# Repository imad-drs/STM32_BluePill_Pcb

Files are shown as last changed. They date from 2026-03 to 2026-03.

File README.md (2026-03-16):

# STM32_BluePill_Pcb
A custom STM32F103C8T6 development board designed in KiCad

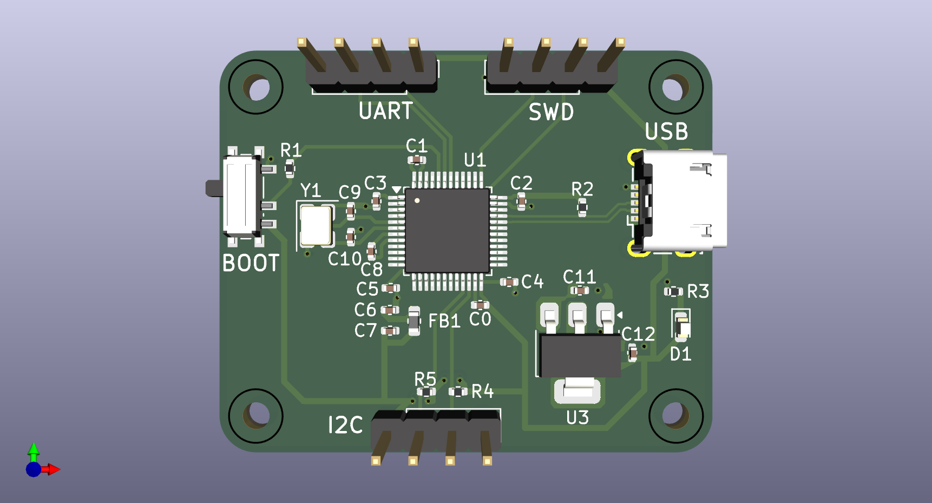
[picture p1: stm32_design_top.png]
Board Render
 

⚠️ Disclaimer: First PCB Project
**Please note:** This is my very first custom PCB design! I reverse-engineered the popular "Blue Pill" board to design this custom circuit in KiCad. It was created as a personal learning exercise to understand the bridge between embedded software and physical hardware. While I put a lot of effort into following best practices, there may be errors. **This project should not be used as an official hardware reference.**

## 🛠️ Project Overview
This repository contains the KiCad project files for a custom microcontroller development board based on the **STM32F103C8T6** (ARM Cortex-M3). 

### Hardware Specifications & Features:
* **PCB Stackup:** Routed on a standard 2-layer board.
* **Connectivity & Debugging:** Includes a dedicated **SWD (Serial Wire Debug)** header for easy flashing/debugging, plus broken-out **UART** and **I2C** pins for external sensor communication.
* **USB Interface:** Integrated Micro-USB Type-B connector for power and data.
* **Clocking:** External crystal oscillator circuit included for precise timing and USB synchronization.
* **User Interface:** Includes a dedicated BOOT button for flashing/configuration and a Power indicator LED.
* **Signal Integrity:** Robust power routing with separated digital and analog ground planes (where applicable).

## ⚡ Technical Deep Dive: Decoupling Capacitors
One of the primary focuses of this project was understanding and implementing proper power delivery. Because microcontrollers switch states millions of times per second, they require instantaneous bursts of current. Traces and power supplies have inherent inductance and cannot deliver this current fast enough, potentially causing the system to crash. 

To ensure stability, I implemented a strict decoupling strategy:
* **Local Decoupling (100nF):** Placed as close as physically possible to each `VDD` and `VBAT` pin. These act as tiny, instant energy reservoirs to handle high-frequency switching.
* **Bulk Decoupling (10uF):** Placed near the microcontroller to act as a larger, general energy reservoir for the IC.
* **Analog Filtering (VDDA):** The analog supply pin is highly sensitive to digital noise. I isolated it from the main digital 3.3V rail using a ferrite bead (120Ω at 100MHz) flanked by a 1uF and 10nF parallel capacitor network to protect the internal Analog-to-Digital Converters (ADCs).

## 📂 Files Included
* Core KiCad project files (`.kicad_pro`, `.kicad_sch`, `.kicad_pcb`).
* `Schematic.pdf`: Exported PDF of the logical circuit map.

---
*Designed by Drias Imad Eddine *

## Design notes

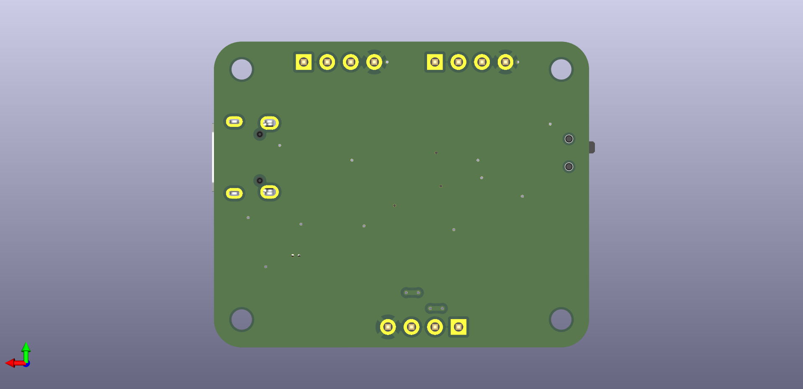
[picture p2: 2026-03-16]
stm32_design_bottom.png

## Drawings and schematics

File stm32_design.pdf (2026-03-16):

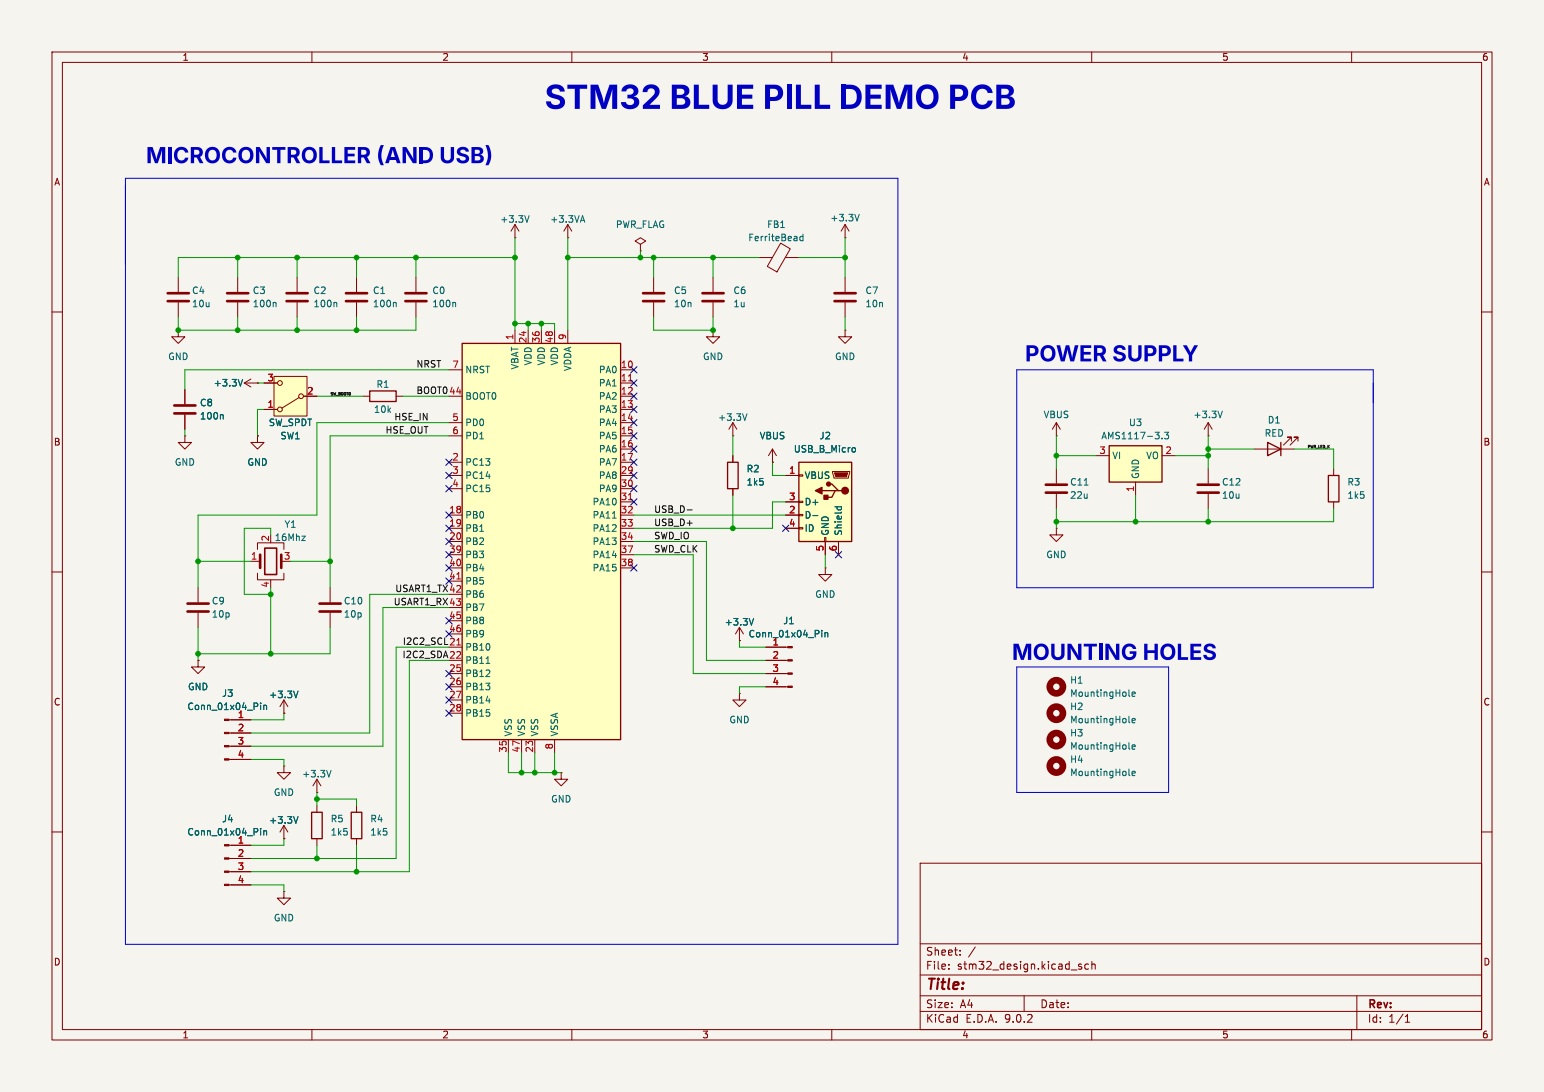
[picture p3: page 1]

1 VSS 47 VDD 24 VSS 23 VDD 36 VDD 48 VSSA

Id: 1/1 Title: File: stm32_design.kicad_sch Sheet: /

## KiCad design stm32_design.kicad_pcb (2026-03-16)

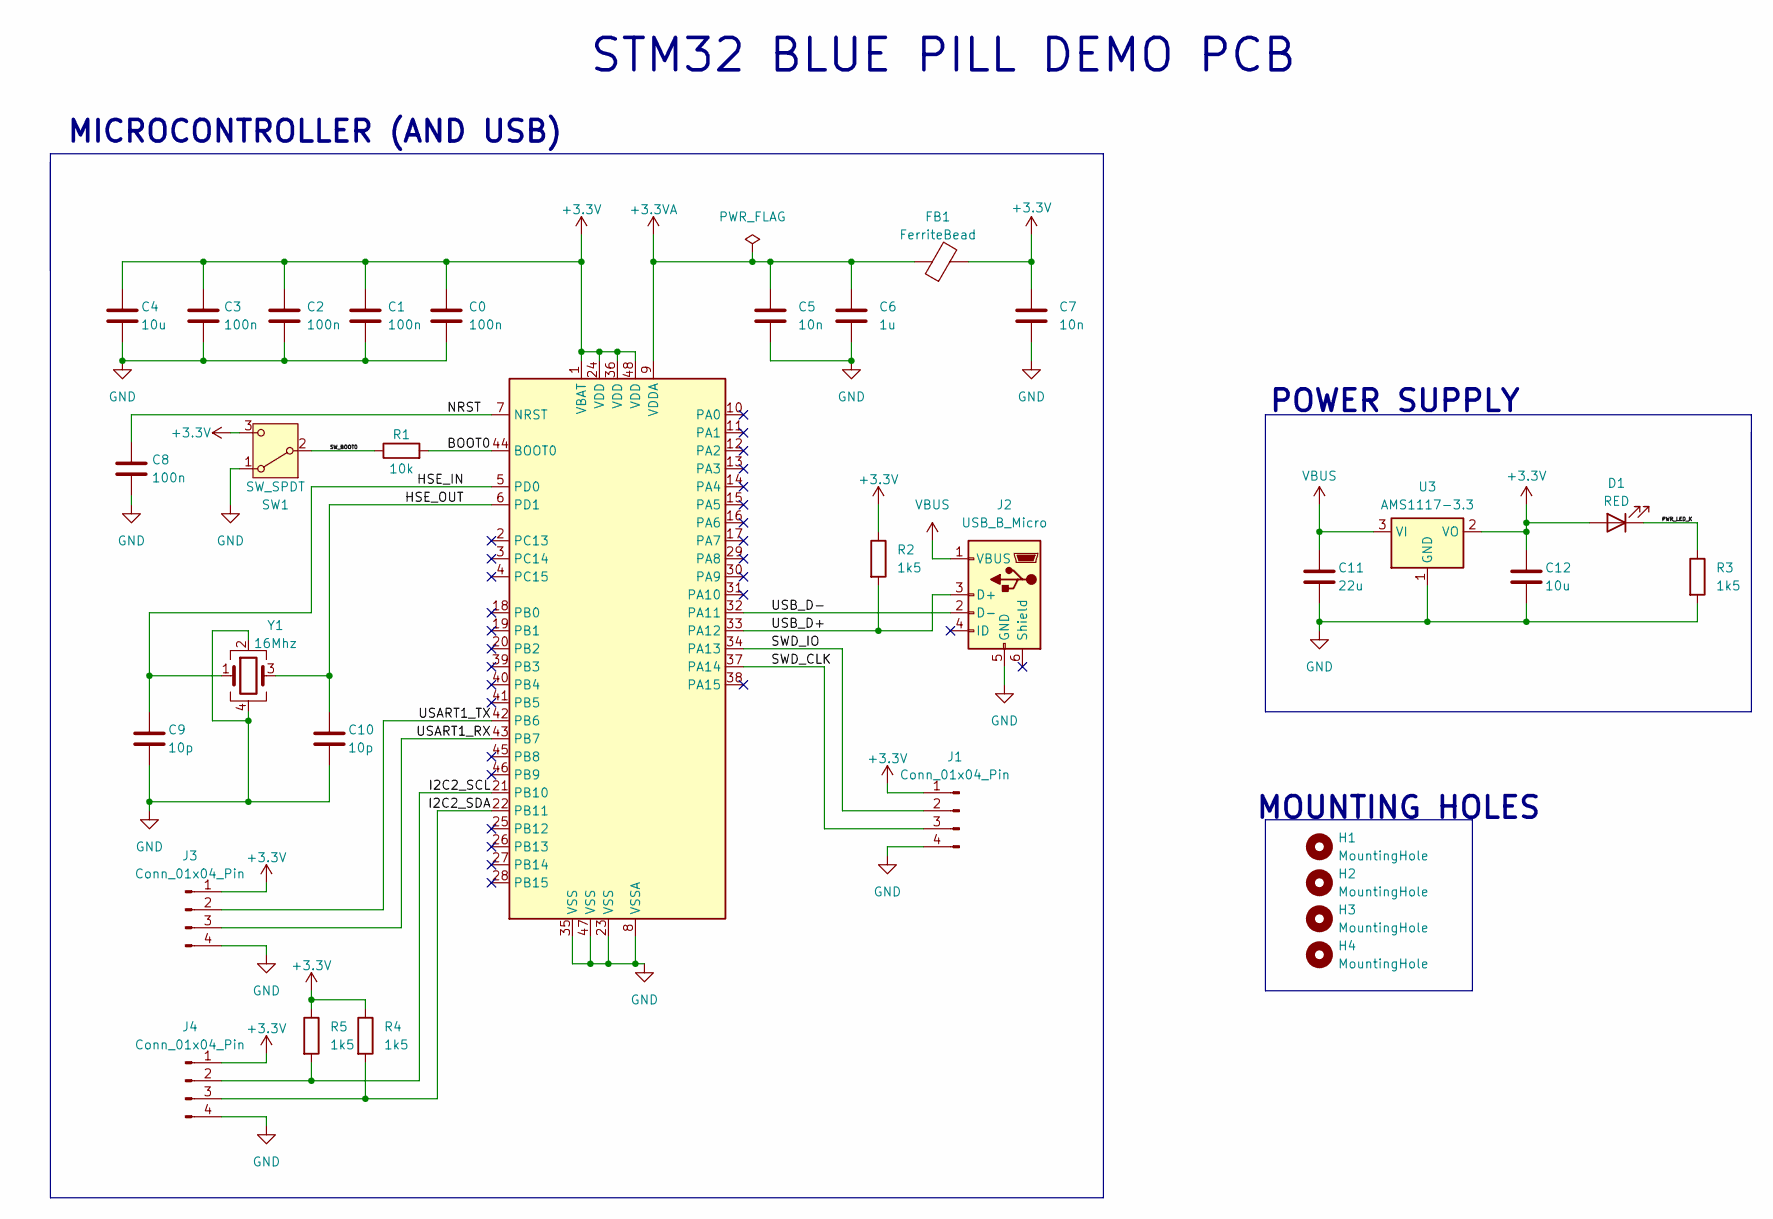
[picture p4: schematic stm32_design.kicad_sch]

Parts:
C0, C1, C2, C3, C8: 100n; C_0402_1005Metric
C4, C12: 10u; C_0402_1005Metric
C5, C7: 10n; C_0402_1005Metric
C6: 1u; C_0402_1005Metric
C9, C10: 10p; C_0402_1005Metric
C11: 22u; C_0402_1005Metric
D1: RED; LED_0603_1608Metric
FB1: FerriteBead; L_0603_1608Metric
H1, H2, H3, H4: MountingHole; MountingHole_2.2mm_M2
J1, J3, J4: Conn_01x04_Pin; PinHeader_1x04_P2.54mm_Vertical
J2: USB_B_Micro; USB_Micro-B_Wuerth_629105150521
R1: 10k; R_0402_1005Metric
R2, R3, R4, R5: 1k5; R_0402_1005Metric
SW1: SW_SPDT; SW_SPDT_PCM12
U1: STM32F103C8Tx; LQFP-48_7x7mm_P0.5mm
U3: AMS1117-3.3; SOT-223-3_TabPin2
Y1: 16Mhz; Crystal_SMD_3225-4Pin_3.2x2.5mm

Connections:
+3.3V: C0.1, C1.1, C2.1, C3.1, C4.1, C7.1, C12.1, D1.2 (A), FB1.2, J1.1, J3.1, J4.1, R2.1, R4.1, R5.1, SW1.3 (C), U1.1 (VBAT), U1.24 (VDD), U1.36 (VDD), U1.48 (VDD), U3.2 (VO)
+3.3VA: C5.1, C6.1, FB1.1, U1.9 (VDDA)
/BOOT0: R1.2, U1.44 (BOOT0)
/HSE_IN: C9.1, U1.5 (PD0), Y1.1
/HSE_OUT: C10.1, U1.6 (PD1), Y1.3
/I2C2_SCL: J4.2, R5.2, U1.21 (PB10)
/I2C2_SDA: J4.3, R4.2, U1.22 (PB11)
/NRST: C8.1, U1.7 (NRST)
/PWR_LED_K: D1.1 (K), R3.1
/SWD_CLK: J1.3, U1.37 (PA14)
/SWD_IO: J1.2, U1.34 (PA13)
/SW_BOOT0: R1.1, SW1.2 (B)
/USART1_RX: J3.3, U1.43 (PB7)
/USART1_TX: J3.2, U1.42 (PB6)
/USB_D+: J2.3 (D+), R2.2, U1.33 (PA12)
/USB_D-: J2.2 (D-), U1.32 (PA11)
GND: C0.2, C1.2, C2.2, C3.2, C4.2, C5.2, C6.2, C7.2, C8.2, C9.2, C10.2, C11.2, C12.2, J1.4, J2.5 (GND), J3.4, J4.4, R3.2, SW1.1 (A), U1.8 (VSSA), U1.23 (VSS), U1.35 (VSS), U1.47 (VSS), U3.1 (GND), Y1.2, Y1.4
VBUS: C11.1, J2.1 (VBUS), U3.3 (VI)

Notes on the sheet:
STM32 BLUE PILL DEMO PCB
POWER SUPPLY
MOUNTING HOLES
MICROCONTROLLER (AND USB)

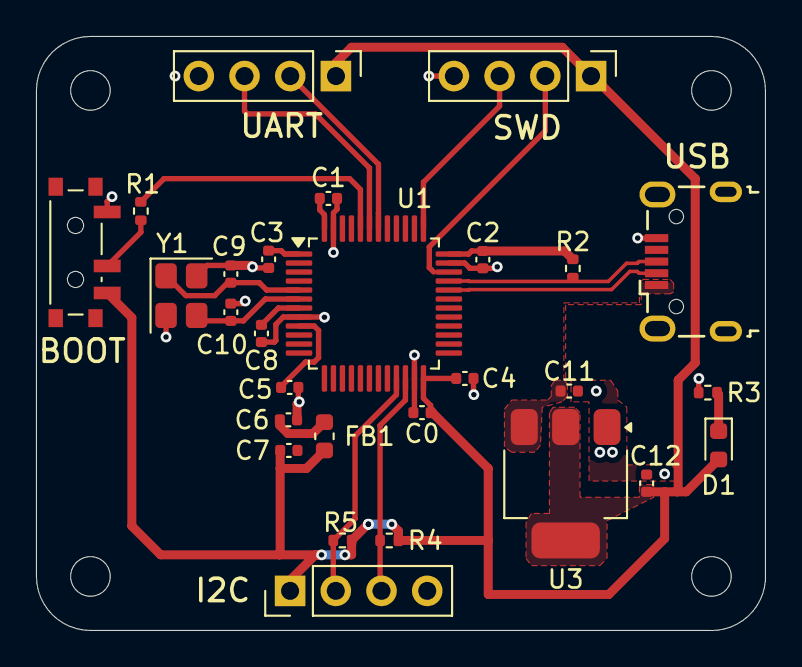
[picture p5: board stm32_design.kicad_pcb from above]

Board: 2 copper layers, 40.5 x 33.0 mm, 32 parts (0 on the bottom side), 18 nets.

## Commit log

2026-03-16 Initial project upload
    [stm32_design.kicad_pcb, stm32_design.kicad_sch]
2026-03-16 Enhance README with project details and specifications
    Added detailed project overview, hardware specifications, and decoupling capacitor strategy to README.
